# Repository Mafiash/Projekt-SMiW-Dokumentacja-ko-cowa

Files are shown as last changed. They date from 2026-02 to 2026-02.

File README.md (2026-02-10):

# Smart LED - Inteligentny Sysytem Oświetlenia LED

**Autor:** Mateusz Smuda
**Sekcja:** 10 
**Nr albumu:** 312441 
**Rok:** 2025 

## Opis Projektu
Projekt "Smart LED" to system automatycznego sterowania oświetleniem LED WS2812B opartym na mikrokontrolerze ESP32-WROOM-32E. System wykorzystuje zaawansowany radar obecności (LD2410C) zamiast tradycyjnych czujników PIR. Dodatkowo barwa światła dostosowuje się do temperatury otoczenia przy użyciu czujnika DHT22, a jasność świecenia jest regulowana automatycznie w zależności od jasności otoczenia za pomocą fotorezystora.

Układ zarządzany jest przez własny serwer WWW postawiony na ESP32, umożliwiający zdalne sterowanie z poziomu przeglądarki (telefon/komputer).

## Główne Funkcjonalności
- **Wykrywanie obecności:** Radar LD2410C (wykrywanie ruchu i bezruchu).
- **Adaptacja barwna:** Zmiana koloru LED w zależności od temperatury (Niebieski <20°C / Zielony / Czerwony >26°C).
- **Adaptacja jasności:** Automatyczne ściemnianie w nocy i rozjaśnianie w dzień.
- **Interfejs WWW:** Panel sterowania (HTML/JS) z podglądem parametrów na żywo.
- **Tryby pracy:** 
  - **AUTO:** Pełna automatyka sensorowa.
  - **MANUAL:** Ręczne ustawianie koloru (RGB) i jasności suwakiem.

## Wykorzystany Sprzęt
1. **Mikrokontroler:** ESP32-WROOM-32E
2. **Oświetlenie:** Taśma LED adresowalna WS2812B (60 diod)
3. **Sensor ruchu:** Radar HLK-LD2410C
4. **Sensor temp/wilg:** DHT22
5. **Sensor światła:** Moduł z fotorezystorem

## Technologie
- **Język:** C++ (Arduino IDE)
- **Web:** HTML, CSS, JavaScript
- **Biblioteki:** Adafruit NeoPixel, DHT Sensor Library, WiFi.h, WebServer.h

## Instrukcja Uruchomienia
1. Podłącz zasilanie 5V.
2. Połącz się z siecią WiFi.

3. Wpisz w przeglądarce adres IP urządzenia.

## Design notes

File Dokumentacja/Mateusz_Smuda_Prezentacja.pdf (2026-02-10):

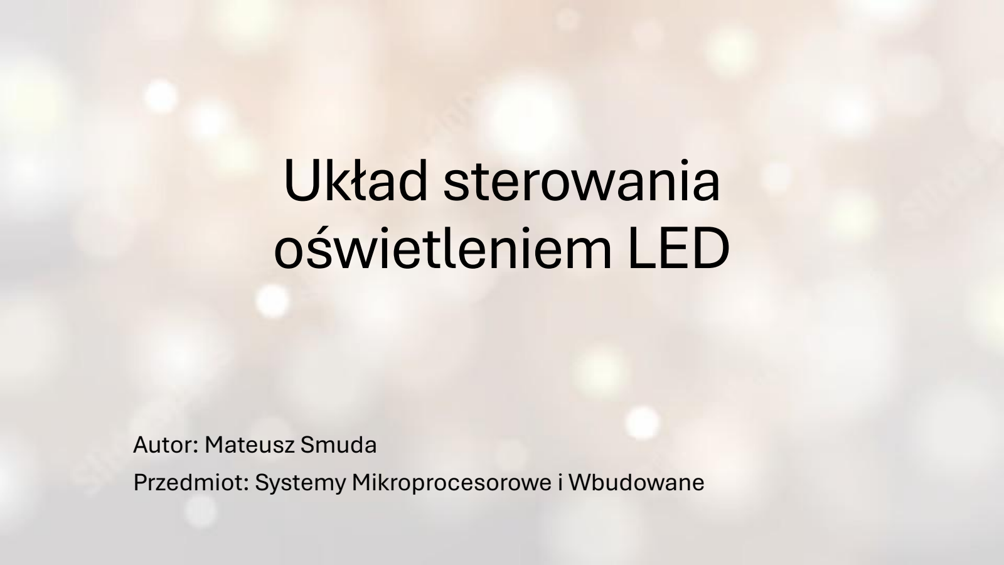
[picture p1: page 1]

# Układ sterowania oświetleniem LED

Autor: Mateusz Smuda
Przedmiot: Systemy Mikroprocesorowe i Wbudowane

## 1. Założenia projektu

- Stworzenie układu sterującego taśmą LED WS2812B.
- Wykorzystanie czujników do automatycznej regulacji zachowania oświetlenia.
- Zmiana koloru LED w zależności od temperatury (DHT22).
- Zmiana jasności w zależności od natężenia światła (fotorezystor).
- Włączanie oświetlenia po wykryciu ruchu przez czujnik LD2410C.
- Dwa tryby pracy: automatyczny i manualny.
- Sterowanie zdalne przez aplikację webową hostowaną na ESP32.

## 2. Analiza układu

- Układ zbiera informacje o temperaturze, natężeniu światła oraz obecności człowieka, a następnie wykorzystuje te dane do odpowiedniego dostosowania barwy i jasności taśmy LED WS2812B.
- System przewiduje dwa tryby pracy: automatyczny i manualny.
- W trybie automatycznym oświetlenie reaguje samoczynnie na dane z czujników
- W trybie manualnym użytkownik sam wybiera parametry światła za pomocą prostej aplikacji webowej. ESP32 pełni rolę jednostki centralnej, obsługuje komunikację z czujnikami oraz generuje sygnały sterujące LED-ami, a dzięki wbudowanemu Wi-Fi umożliwia wygodne sterowanie z poziomu przeglądarki.

## 3. Schemat układu

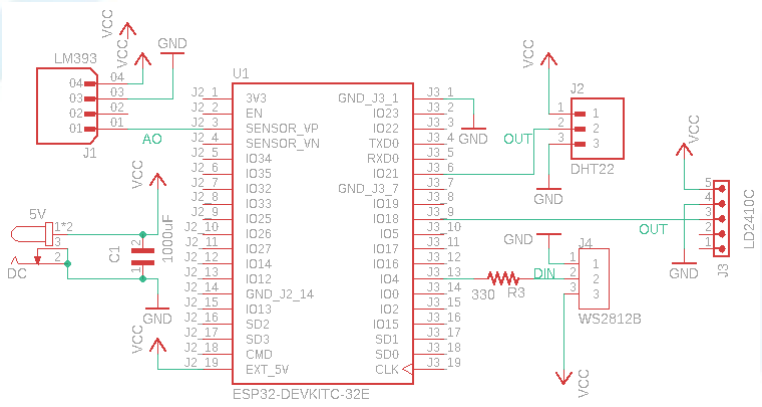
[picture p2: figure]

## 4. Schemat PCB

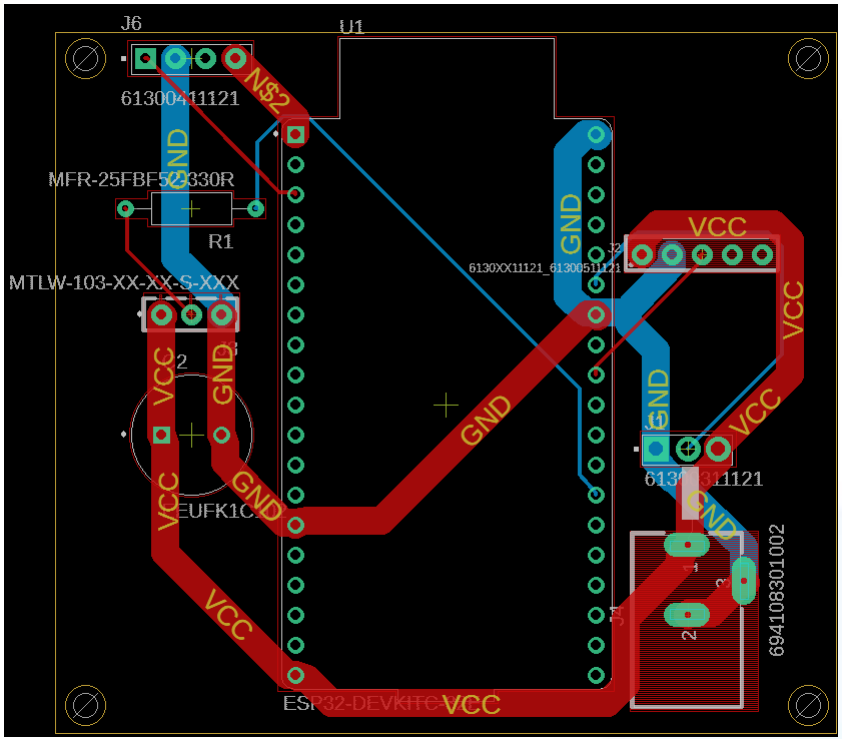
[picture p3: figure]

## 5. Dobór części

- ESP32-WROOM-32E – główny mikrokontroler, obsługa Wi-Fi, sterowanie LED i czujnikami.
- Taśma LED RGB WS2812B – adresowalne diody RGB, umożliwiają płynną zmianę kolorów i efektów.
- Czujnik DHT22(AM2302) – pomiar temperatury i wilgotności, wykorzystany do sterowania barwą LED.
- Czujnik LD2410C – radarowy czujnik ruchu wykrywający obecność osoby.
- Czujnik światła jako moduł wyposażony w fotorezystor – pomiar natężenia światła, regulacja jasności LED.

## ESP32-DevKitC-32E

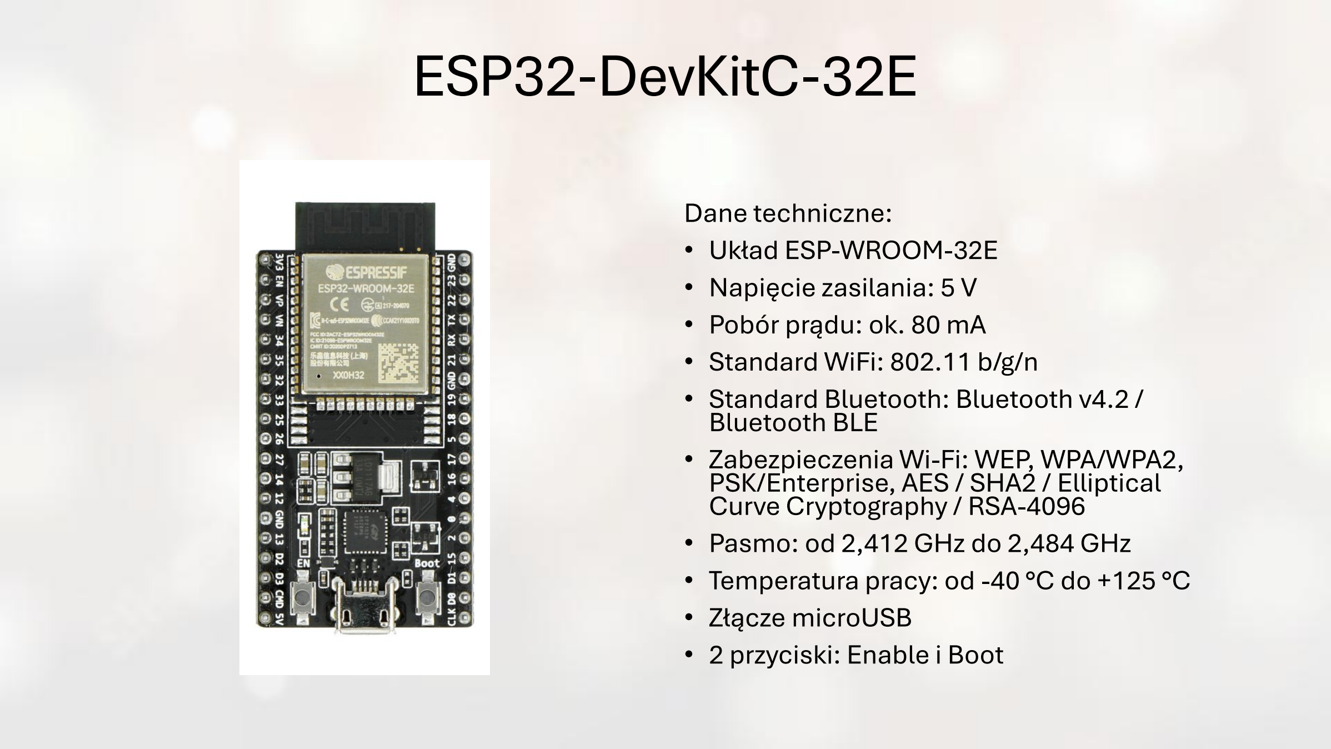
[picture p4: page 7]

Dane techniczne:
- Układ ESP-WROOM-32E
- Napięcie zasilania: 5 V
- Pobór prądu: ok. 80 mA
- Standard WiFi: 802.11 b/g/n
- Standard Bluetooth: Bluetooth v4.2 / Bluetooth BLE
- Zabezpieczenia Wi-Fi: WEP, WPA/WPA2, PSK/Enterprise, AES / SHA2 / Elliptical Curve Cryptography / RSA-4096
- Pasmo: od 2,412 GHz do 2,484 GHz
- Temperatura pracy: od -40 °C do +125 °C
- Złącze microUSB
- 2 przyciski: Enable i Boot

## Taśma LED RGB WS2812B

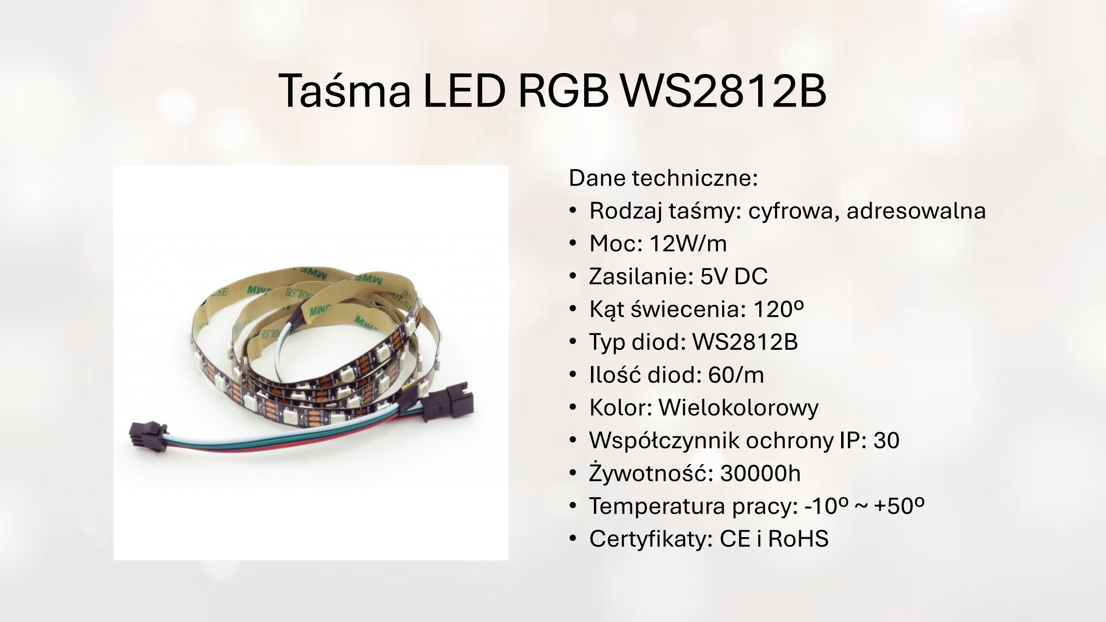
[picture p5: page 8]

Dane techniczne:
- Rodzaj taśmy: cyfrowa, adresowalna
- Moc: 12W/m
- Zasilanie: 5V DC
- Kąt świecenia: 120º
- Typ diod: WS2812B
- Ilość diod: 60/m
- Kolor: Wielokolorowy
- Współczynnik ochrony IP: 30
- Żywotność: 30000h
- Temperatura pracy: -10º ~ +50º
- Certyfikaty: CE i RoHS

## Czujnik AM2302(DHT22)

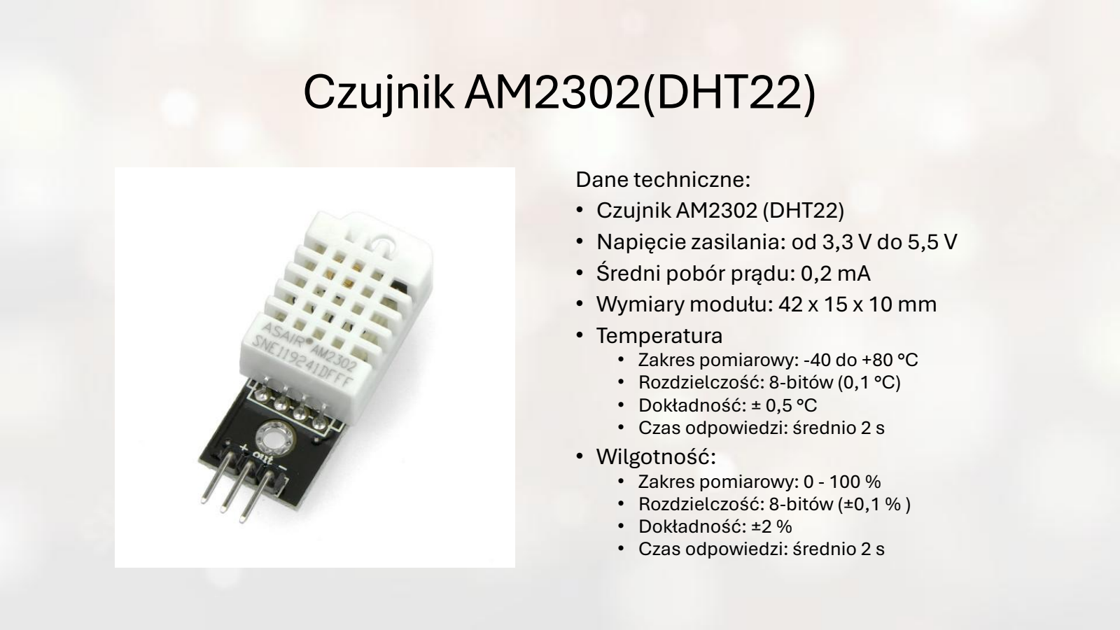
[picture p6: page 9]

Dane techniczne:
- Czujnik AM2302 (DHT22)
- Napięcie zasilania: od 3,3 V do 5,5 V
- Średni pobór prądu: 0,2 mA
- Wymiary modułu: 42 x 15 x 10 mm
- Temperatura
- Zakres pomiarowy: -40 do +80 °C
- Rozdzielczość: 8-bitów (0,1 °C)
- Dokładność: ± 0,5 °C
- Czas odpowiedzi: średnio 2 s
- Wilgotność:
- Zakres pomiarowy: 0 - 100 %
- Rozdzielczość: 8-bitów (±0,1 % )
- Dokładność: ±2 %
- Czas odpowiedzi: średnio 2 s

## Czujnik obecności człowieka HLK-LD2410C

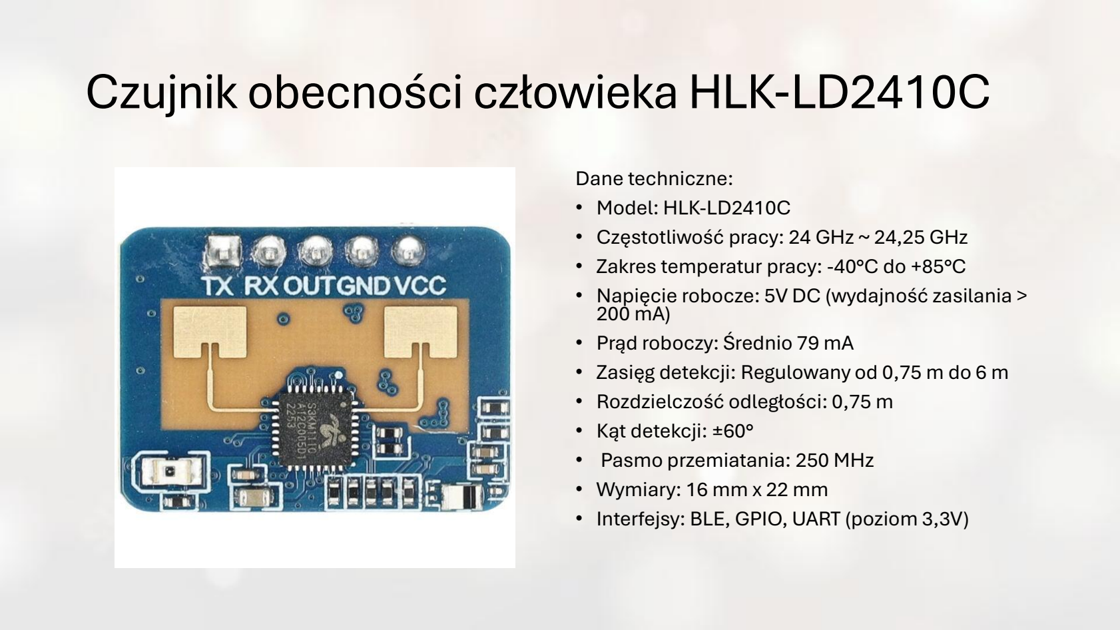
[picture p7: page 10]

Dane techniczne:
- Model: HLK-LD2410C
- Częstotliwość pracy: 24 GHz ~ 24,25 GHz
- Zakres temperatur pracy: -40°C do +85°C
- Napięcie robocze: 5V DC (wydajność zasilania > 200 mA)
- Prąd roboczy: Średnio 79 mA
- Zasięg detekcji: Regulowany od 0,75 m do 6 m
- Rozdzielczość odległości: 0,75 m
- Kąt detekcji: ±60°
- Pasmo przemiatania: 250 MHz
- Wymiary: 16 mm x 22 mm
- Interfejsy: BLE, GPIO, UART (poziom 3,3V)

## Czujnik światła fotorezystor

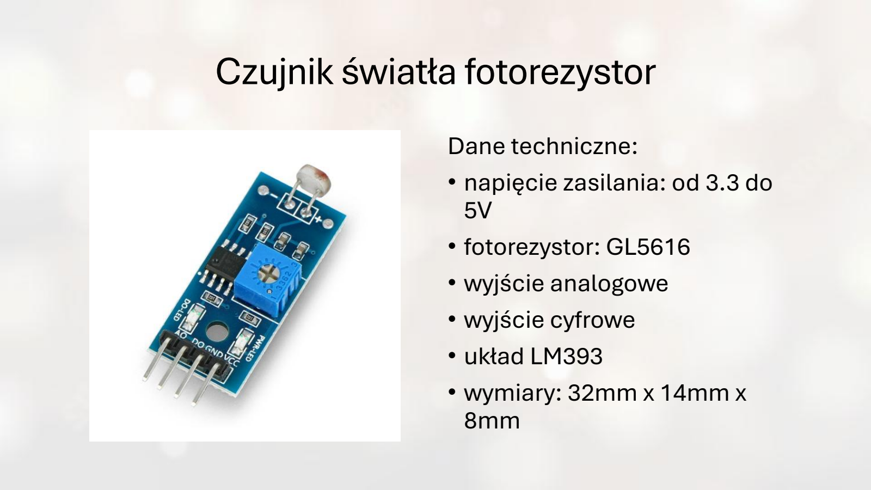
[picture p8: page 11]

Dane techniczne:
- napięcie zasilania: od 3.3 do 5V
- fotorezystor: GL5616
- wyjście analogowe
- wyjście cyfrowe
- układ LM393
- wymiary: 32mm x 14mm x
8mm

## 6. Kosztorys

ESP32-DevKitC-32E | 36 zł
Zasilacz | 50 zł
Czujnik temperatury i wilgotności DHT22 (AM2302) | 45 zł
Czujnik obecności człowieka HLK-LD2410C 24GHz BLE UART | 20 zł
Czujnik światła LDR rezystancyjny | 5 zł
1m taśma WS2812B argb 5V 60 diod/m | 30 zł
Łączna kwota z kosztami dodatkowymi: | 200 zł

## 7. Działanie układu

- Po uruchomieniu systemu ESP32 inicjalizuje taśmę LED, czujniki oraz moduł komunikacyjny Wi-Fi.
- W trybie automatycznym mikrokontroler cyklicznie odczytuje temperaturę, natężenie światła i sygnał z czujnika ruchu. Na tej podstawie dobiera kolor LED zależnie od temperatury oraz ustala jasność odpowiednią do poziomu oświetlenia otoczenia.
- Gdy radar wykryje obecność osoby, taśma LED zostaje automatycznie włączona, a brak ruchu powoduje jej wyłączenie.
- W trybie manualnym logika automatyczna jest pomijana, a ESP32 reaguje jedynie na polecenia użytkownika przesyłane z aplikacji webowej.
- Panel dostępny w przeglądarce pozwala ustawić kolor, jasność i przełączyć tryb pracy. Dzięki temu układ może pracować zarówno jako autonomiczne oświetlenie reagujące na otoczenie, jak i jako źródło światła sterowane zdalnie.

## 8. Instrukcja użytkownika

- Podłącz układ do zasilacza 5 V.
- Po włączeniu ESP32 uruchomi aplikację webową.
- Otwórz przeglądarkę i wejdź na adres IP ESP32.
- Wybierz tryb pracy: automatyczny lub manualny.
- W trybie manualnym ustaw kolor i jasność diod LED.
- W trybie automatycznym układ pracuje samodzielnie, reagując na warunki otoczenia.
- Możliwość monitorowania temperatury, jasności i wykrywania ruchu bezpośrednio w panelu.

## 9. Wnioski

Projekt pozwolił na stworzenie w pełni funkcjonalnego, inteligentnego układu sterowania oświetleniem.
Zastosowanie ESP32 umożliwiło integrację wielu czujników oraz funkcjonalności sieciowych w jednym urządzeniu.
System jest skalowalny i łatwy do rozbudowy o dodatkowe funkcje. Dzięki projektowi poznano praktyczne zastosowanie mikrokontrolerów rodziny ESP32 oraz różnych czujników monitorujących otoczenie.
Projekt umożliwił także zapoznanie się z programem EAGLE 9.6.2 który pozwolił na zaprojektowanie schematu układu oraz płytki PCB.

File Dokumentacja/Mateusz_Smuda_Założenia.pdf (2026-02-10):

Mateusz Smuda, 312441, sekcja 10, 2025
Temat:
Układ sterowania LED z czujnikiem ruchu, czujnikiem temperatury oraz czujnikiem światła Założenia projektu:
- Stworzenie układu sterującego taśmą LED WS2812B.
- Wykorzystanie czujników do automatycznej regulacji zachowania oświetlenia.
- Zmiana koloru LED w zależności od temperatury (DHT22).
- Zmiana jasności w zależności od natężenia światła (fotorezystor).
- Włączanie oświetlenia po wykryciu ruchu przez czujnik LD2410C.
- Dwa tryby pracy: automatyczny i manualny.
- Sterowanie zdalne przez aplikację webową hostowaną na ESP32.
Celem projektu jest stworzenie inteligentnego systemu oświetlenia LED, który łączy funkcje automatycznej regulacji światła z możliwością zdalnego sterowania. Układ zbiera informacje o temperaturze, natężeniu światła oraz wykryciu ruchu, a następnie wykorzystuje te dane do odpowiedniego dostosowania barwy i jasności taśmy LED WS2812B. System przewiduje dwa tryby pracy: automatyczny i manualny. W trybie automatycznym oświetlenie reaguje samoczynnie na dane z czujników, natomiast w trybie manualnym użytkownik sam wybiera parametry światła za pomocą prostej aplikacji webowej. ESP32 pełni rolę jednostki centralnej, obsługuje komunikację z czujnikami oraz generuje sygnały sterujące LED-ami, a dzięki wbudowanemu Wi-Fi umożliwia wygodne sterowanie z poziomu przeglądarki.
Użyte komponenty:
- Płytka rozwojowa z wbudowanym modułem ESP32-WROOM-E
- adresowalny pasek LED(WS2812B)
- czujnik temperatury(DHT22)
- czujnik ruchu(LD2410C)
- czujnik światła(fotorezystor)

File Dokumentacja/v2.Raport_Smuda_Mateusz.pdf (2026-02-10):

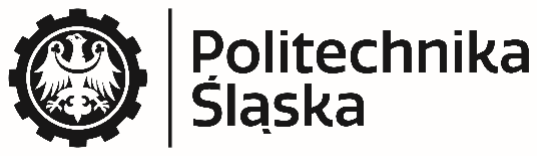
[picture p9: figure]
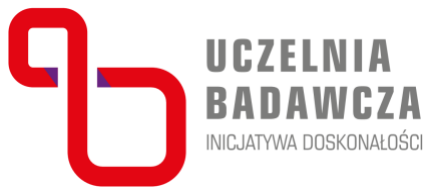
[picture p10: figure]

# Raport końcowy

Rodzaj zajęć

# Projekt

Przedmiot

# Systemy Mikroprocesorowe i Wbudowane

Rok akademicki | Miasto | Kierunek | Semestr | Prowadzący | Grupa | Sekcja
2025/2026 | G | INF | 5 | GB | 5 | 10
Planowany termin wykonywania ćwiczenia | Faktyczny termin wykonania ćwiczenia
Data | Godzina | Data | Godzina
02.02.2026 | 14:00
Numer ćwiczenia | Temat ćwiczenia
| Układ sterowania oświetleniem LED

Skład sekcji
| Imię i nazwisko | Uwagi
1 | Mateusz Smuda

1. Temat projektu i opis założeń z opisem funkcji urządzenia.

Temat:

Układ sterowania LED z czujnikiem ruchu, czujnikiem temperatury oraz czujnikiem światła

Założenia projektu:

- Stworzenie układu sterującego taśmą LED WS2812B.
- Wykorzystanie czujników do automatycznej regulacji zachowania oświetlenia.
- Zmiana koloru LED w zależności od temperatury (DHT22).
- Zmiana jasności w zależności od natężenia światła (fotorezystor).
- Włączanie oświetlenia po wykryciu ruchu przez czujnik LD2410C.
- Dwa tryby pracy: automatyczny i manualny.
- Sterowanie zdalne przez aplikację webową hostowaną na ESP32.

### 2. Analiza zadania z uzasadnieniem wyboru elementów elektronicznych i narzędzi użytych do

realizacji projektu.

Celem projektu jest stworzenie inteligentnego systemu oświetlenia LED, który łączy funkcje automatycznej regulacji światła z możliwością zdalnego sterowania. Układ zbiera informacje o temperaturze, natężeniu światła oraz wykryciu ruchu, a następnie wykorzystuje te dane do odpowiedniego dostosowania barwy i jasności taśmy LED WS2812B. System przewiduje dwa tryby pracy: automatyczny i manualny. W trybie automatycznym oświetlenie reaguje samoczynnie na dane z czujników, natomiast w trybie manualnym użytkownik sam wybiera parametry światła za pomocą prostej aplikacji webowej. ESP32 pełni rolę jednostki centralnej, obsługuje komunikację z czujnikami oraz generuje sygnały sterujące LED-ami, a dzięki wbudowanemu Wi-Fi umożliwia wygodne sterowanie z poziomu przeglądarki.

Do realizacji projektu wybrano mikrokontroler ESP32 ze względu na:

- wbudowany moduł Wi-Fi,
- dużą liczbę wejść/wyjść,
- wysoką wydajność,
- szerokie wsparcie bibliotek programistycznych.

Taśma LED WS2812B została wybrana ze względu na możliwość indywidualnego adresowania diod, co pozwala na precyzyjną kontrolę koloru i jasności przy użyciu jednego pinu sterującego.

Czujnik LD2410C wykorzystuje technologię radarową, co umożliwia wykrywanie obecności człowieka niezależnie od warunków oświetleniowych, wybrany został przez swoją precyzję pomiarów i możliwość wygodnego dostosowywania parametrów.

Czujnik DHT22 umożliwia pomiar temperatury został on wybrany za dokładność i możliwość łatwego montażu.

Moduł fotorezystora pozwala na ocenę poziomu oświetlenia otoczenia został wybrany z powodu łatwości obsługi.

Do programowania wykorzystano środowisko Arduino IDE, które umożliwia szybkie prototypowanie oraz łatwą integrację bibliotek obsługujących zastosowane komponenty.

### 3. Specyfikacja wewnętrzna:

a. Schemat blokowy i ideowy urządzenia.

Schemat blokowy:

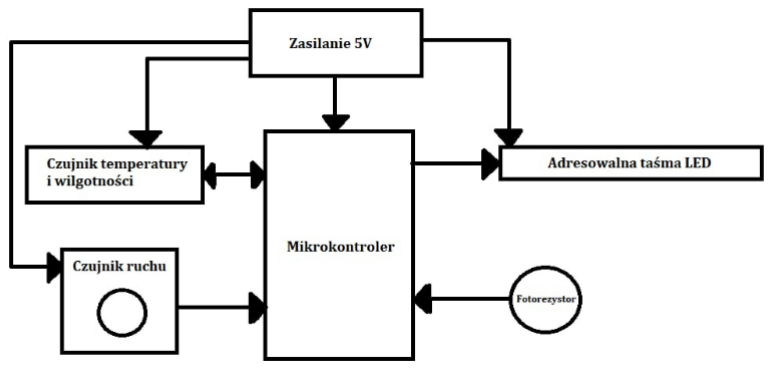
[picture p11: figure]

Schemat ideowy z podpisanymi modułami bez prowadzenia długich ścieżek w celu lepszej widoczności i sprawdzenia poprawności układu:

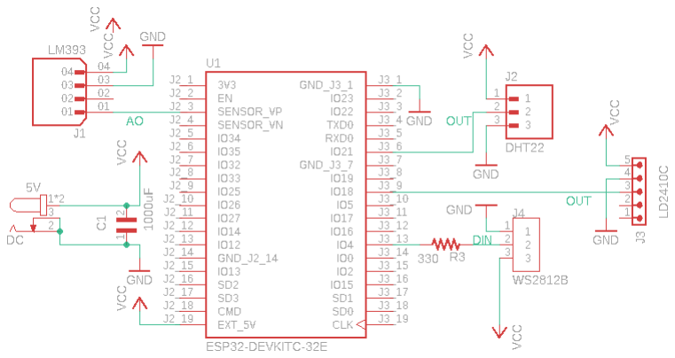
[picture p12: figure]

Schematu użyty do zaprojektowania płytki PCB ze ścieżkami:

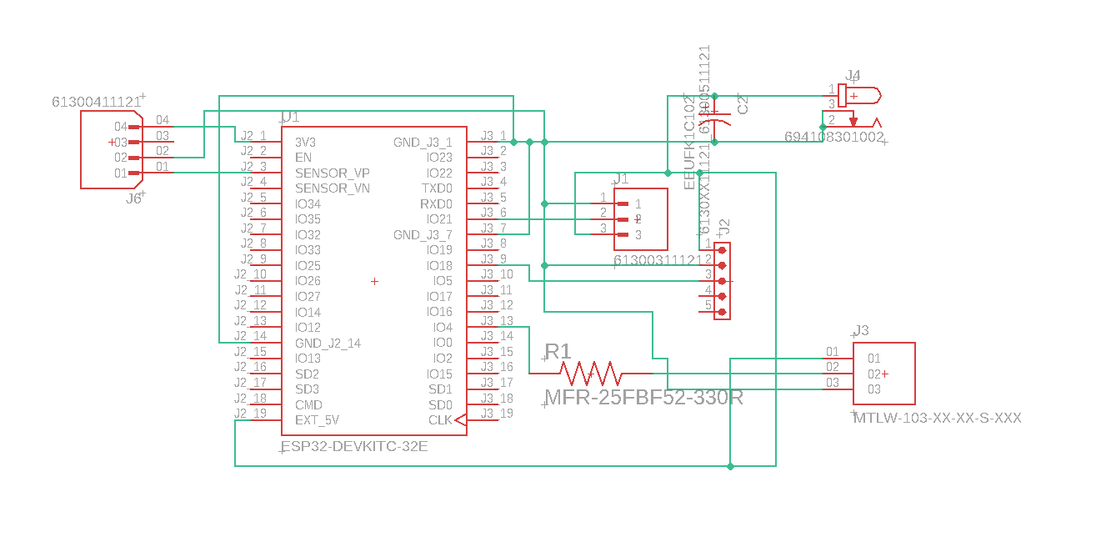
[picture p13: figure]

b. Opis funkcji poszczególnych bloków układu, szczegółowy opis działania ważniejszych elementów układu.

ESP32 – jednostka centralna systemu, przetwarza dane z czujników, steruje diodami LED oraz obsługuje komunikację Wi-Fi.

LD2410C – czujnik ruchu, generuje sygnał informujący o wykryciu ruchu.

DHT22 – czujnik temperatury, dostarcza danych do regulacji koloru LED.

Fotorezystor – mierzy poziom światła otoczenia, na podstawie którego regulowana jest jasność LED.

WS2812B – element generujący światło zgodnie z pomiarami czujników.

c. Schemat montażowy obejmujący projekt płytki drukowanej, rozmieszczenie elementów na płytce.

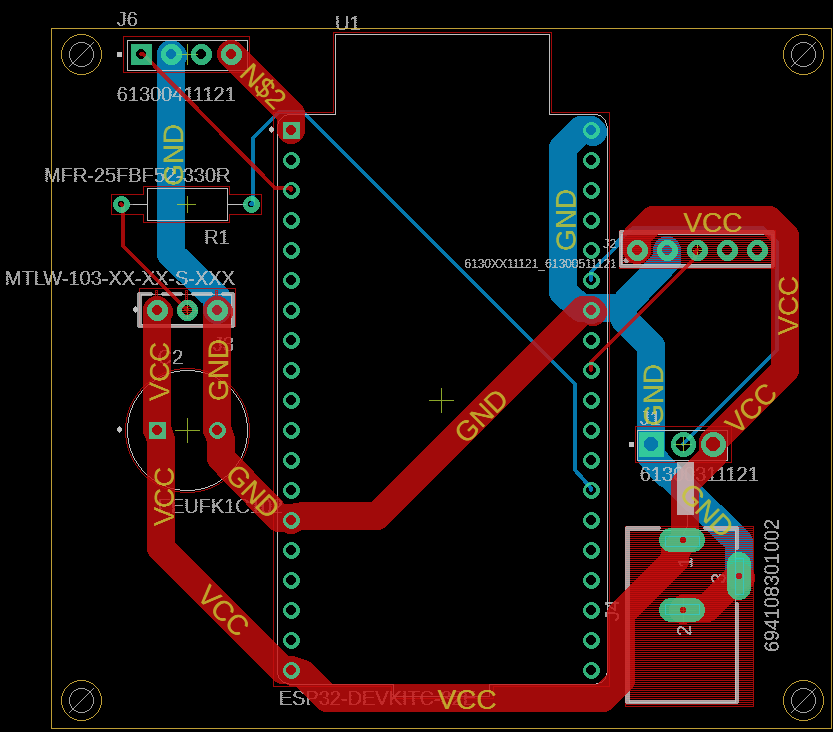
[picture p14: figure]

Lista elementów:

ESP32-DEVKITC-32E

694108301002 – złącze zasilania DC 2.5mm/5.5mm

Złącza goldpin męskie 3 pin/4 pin oraz 5 pin o rastrze 2.54mm do podpięcia czujników(DNT22,LD2410C,moduł fotorezystor) oraz adresowalnego paska LED WS2812B

Rezystor 330Ohm

Kondensator 1000uF

d. Algorytm oprogramowania urządzenia

Algorytm działania oprogramowania opiera się na pętli głównej programu, w której mikrokontroler ESP32 cyklicznie obsługuje komunikację sieciową, odczytuje dane z czujników oraz steruje taśmą LED. Po uruchomieniu urządzenia następuje inicjalizacja mikroprocesora, czujników oraz połączenia Wi-Fi. Następnie uruchamiany jest serwer WWW, który udostępnia panel sterowania użytkownikowi.

W głównej pętli programu realizowane są następujące kroki:

1. Obsługa żądań HTTP z aplikacji webowej.
2. Cykliczny odczyt temperatury, natężenia światła oraz stanu czujnika ruchu.

3. Sprawdzenie aktualnego trybu pracy (automatyczny lub manualny).
4. W trybie automatycznym – obliczenie koloru i jasności LED na podstawie danych z czujników.
5. W trybie manualnym – ustawienie parametrów LED zgodnie z poleceniami użytkownika.
6. Aktualizacja stanu taśmy LED.

Główny kod programu do sterowania:

#include <WiFi.h>

#include <WebServer.h>

#include <Adafruit_NeoPixel.h> #include <DHT.h>

#include "index.h"

const char* ssid = "HUAWEI Mate 10 Pro"; const char* password = "59befa2de9a3";

#define LED_PIN | 4

#define RADAR_PIN | 18

#define DHT_PIN | 21

#define LDR_PIN | 36

#define NUM_PIXELS 60

#define DHT_TYPE DHT22

Adafruit_NeoPixel pixels(NUM_PIXELS, LED_PIN, NEO_GRB + NEO_KHZ800); DHT dht(DHT_PIN, DHT_TYPE);
WebServer server(80);

const unsigned long CZAS_SWIECENIA = 10000; unsigned long ostatniRuchCzas = 0; unsigned long ostatniOdczytSensorow = 0;

bool trybAuto = true;
bool manualState = false;
uint32_t manualColor = 0;
int manualBrightness = 50;

float temperatura = 0.0;
int jasnoscLDR = 0;
bool wykrytoRuch = false;

void setup() {
Serial.begin(9600);

pinMode(RADAR_PIN, INPUT_PULLDOWN); pinMode(LDR_PIN, INPUT);

dht.begin();
pixels.begin();
pixels.setBrightness(100); pixels.show();

Serial.print("Łączenie z WiFi"); WiFi.begin(ssid, password);
while (WiFi.status() != WL_CONNECTED) { delay(500);
Serial.print(".");
}
Serial.println("\nPołączono!"); Serial.print("Adres IP strony: http://"); Serial.println(WiFi.localIP());

server.on("/", []() {
server.send(200, "text/html", index_html); });

server.on("/status", []() {
String json = "{";
json += "\"temp\":" + String(temperatura) + ","; json += "\"ldr\":" + String(jasnoscLDR) + ","; json += "\"radar\":" + String(wykrytoRuch) + ","; json += "\"modeAuto\":" + String(trybAuto); json += "}";
server.send(200, "application/json", json);
});

server.on("/set", handleControl);

server.begin();
}

void loop() {
server.handleClient();

unsigned long aktualnyCzas = millis();

if (aktualnyCzas - ostatniOdczytSensorow > 2000) { float t = dht.readTemperature();
if (!isnan(t)) temperatura = t;

jasnoscLDR = analogRead(LDR_PIN);

wykrytoRuch = (digitalRead(RADAR_PIN) == HIGH);

ostatniOdczytSensorow = aktualnyCzas;

}

if (trybAuto) {
logikaAutomatyczna(aktualnyCzas); } else {
logikaManualna();
}
}

void logikaAutomatyczna(unsigned long czas) { int stanRadaru = digitalRead(RADAR_PIN);

if (stanRadaru == HIGH) {
ostatniRuchCzas = czas;
}

if (czas - ostatniRuchCzas < CZAS_SWIECENIA) {

uint32_t kolor;
if (temperatura < 20.0) | kolor = pixels.Color(0, 0, 255);
else if (temperatura > 26.0) kolor = pixels.Color(255, 0, 0);
else | kolor = pixels.Color(0, 255, 0);

int jasnoscPWM = map(jasnoscLDR, 0, 4095, 255, 10); jasnoscPWM = constrain(jasnoscPWM, 10, 255);

pixels.setBrightness(jasnoscPWM); fillStrip(kolor);

} else {
pixels.clear();
pixels.show();
}
}

void logikaManualna() {
pixels.setBrightness(manualBrightness);

if (manualState) {
if (manualColor == 0) manualColor = pixels.Color(255, 255, 255); fillStrip(manualColor);
} else {
pixels.clear();
pixels.show();
}
}

void handleControl() {
if (server.hasArg("mode")) {

String m = server.arg("mode");
if (m == "auto") trybAuto = true; if (m == "manual") trybAuto = false; }

if (server.hasArg("manual")) {
manualState = (server.arg("manual").toInt() == 1); }

if (server.hasArg("brightness")) {
manualBrightness = server.arg("brightness").toInt(); }

if (server.hasArg("color")) {
String hex = server.arg("color");
long number = strtol(hex.c_str(), NULL, 16); int r = number >> 16;
int g = (number >> 8) & 0xFF;
int b = number & 0xFF;
manualColor = pixels.Color(r, g, b); }
server.send(200, "text/plain", "OK"); }

void fillStrip(uint32_t color) { for(int i=0; i<NUM_PIXELS; i++) { pixels.setPixelColor(i, color); }
pixels.show();
}

Kod interfejsu strony internetowej:

const char index_html[] PROGMEM = R"rawliteral( <!DOCTYPE html>
<html lang="pl">
<head>
<meta charset="UTF-8">
<meta name="viewport" content="width=device-width, initial-scale=1"> <title>Smart Schody - Panel</title>
<style>
body { font-family: 'Segoe UI', Arial, sans-serif; background-color: #1a1a1a; color: #f0f0f0; text-align: center; margin: 0; padding: 20px; } h1 { color: #00d2ff; margin-bottom: 5px; }
h3 { color: #aaa; margin-top: 0; }

.card { background-color: #2d2d2d; max-width: 400px; margin: 20px auto; padding: 25px; border-radius: 15px; box-shadow: 0 10px 20px rgba(0,0,0,0.5); }

.sensor-grid { display: grid; grid-template-columns: 1fr 1fr; gap: 15px; margin-bottom: 20px; }
.sensor-box { background: #383838; padding: 15px; border-radius: 10px; } .val { font-size: 1.8rem; font-weight: bold; color: #fff; }
.label { font-size: 0.9rem; color: #888; }

.btn-group { display: flex; justify-content: center; gap: 10px; margin: 20px 0; }
button { padding: 12px 20px; font-size: 16px; border: none; border-radius: 8px; cursor: pointer; transition: 0.2s; font-weight: bold; width: 100%; }

.active { border: 2px solid white; transform: scale(1.05); }
.btn-auto { background-color: #007bff; color: white; }
.btn-man { background-color: #ffc107; color: black; }

.manual-controls { background: #444; padding: 15px; border-radius: 10px; margin-top: 15px; }
.toggle-btn { padding: 15px; width: 100%; margin-bottom: 10px; font-size: 1.2rem; }
.on { background-color: #28a745; color: white; }
.off { background-color: #dc3545; color: white; }

input[type="color"] { width: 100%; height: 50px; border: none; cursor: pointer; border-radius: 5px; }
input[type=range] { width: 100%; margin: 10px 0; }
</style>
</head>
<body>

<h1>Smart Schody</h1>
<h3>Panel Sterowania</h3>

<div class="card">
<div class="sensor-grid">
<div class="sensor-box">
<div class="label">Temperatura</div>
<div class="val"><span id="temp">--</span> °C</div> </div>
<div class="sensor-box">
<div class="label">Jasność (LDR)</div>
<div class="val"><span id="ldr">--</span></div> </div>
</div>

<div style="font-size: 0.9rem; color: #bbb; margin-bottom: 15px;">
Status Radaru: <span id="radar" style="font-weight:bold; color:orange">--</span>
</div>

<hr style="border-color: #444;">

<div class="btn-group">
<button id="btnAuto" class="btn-auto" onclick="setMode('auto')">TRYB AUTO</button>
<button id="btnMan" class="btn-man" onclick="setMode('manual')">TRYB RĘCZNY</button>
</div>

<div id="manualPanel" class="manual-controls" style="display:none;"> <button id="mainSwitch" class="toggle-btn off" onclick="toggleLed()">LED: WYŁĄCZONE</button>
<label style="display:block; margin: 10px 0 5px;">Wybierz Kolor:</label> <input type="color" id="colorPicker" value="#ffffff" onchange="updateColor()">
<label style="display:block; margin: 15px 0 5px;">Jasność: <span id="brightVal">50</span></label>
<input type="range" min="10" max="255" value="50" id="brightSlider" oninput="updateBrightness(this.value)" onchange="updateBrightness(this.value)">
</div>
</div>

<script>
let isManualOn = false;

setInterval(getData, 1500);

function getData() {
fetch('/status').then(response => response.json()).then(data => { document.getElementById("temp").innerText = data.temp.toFixed(1); document.getElementById("ldr").innerText = data.ldr; document.getElementById("radar").innerText = data.radar ? "Wykryto Ruch" : "Czuwanie";

if (data.modeAuto) {
document.getElementById("btnAuto").classList.add("active"); document.getElementById("btnMan").classList.remove("active"); document.getElementById("manualPanel").style.display = "none"; } else {
document.getElementById("btnAuto").classList.remove("active"); document.getElementById("btnMan").classList.add("active"); document.getElementById("manualPanel").style.display = "block"; }
});
}

function setMode(mode) {

fetch('/set?mode=' + mode); setTimeout(getData, 200);
}

function toggleLed() {
isManualOn = !isManualOn;
let btn = document.getElementById("mainSwitch"); if(isManualOn) {
btn.innerText = "LED: WŁĄCZONE"; btn.className = "toggle-btn on"; fetch('/set?manual=1');
} else {
btn.innerText = "LED: WYŁĄCZONE"; btn.className = "toggle-btn off"; fetch('/set?manual=0');
}
}

function updateColor() {
var color = document.getElementById("colorPicker").value.substring(1); fetch('/set?color=' + color);
if(!isManualOn) toggleLed();
}

function updateBrightness(val) { document.getElementById("brightVal").innerText = val; fetch('/set?brightness=' + val);
if(!isManualOn) toggleLed();
}

window.onload = getData;
</script>
</body>
</html>
)rawliteral";
e. Opis wszystkich zmiennych.
- ssid, password – dane sieci Wi-Fi, do której łączy się ESP32.
- LED_PIN – pin sterujący taśmą WS2812B.
- RADAR_PIN – pin wejściowy podłączony do wyjścia OUT czujnika LD2410C.
- DHT_PIN – pin komunikacyjny czujnika DHT22.
- LDR_PIN – wejście analogowe do pomiaru natężenia światła.
- NUM_PIXELS – liczba diod LED w taśmie.
- CZAS_SWIECENIA – czas świecenia LED po ostatnim wykryciu ruchu.
- ostatniRuchCzas – czas ostatniego wykrycia ruchu.
- ostatniOdczytSensorow – znacznik czasu ostatniego odczytu czujników.
- trybAuto – flaga określająca tryb pracy (automatyczny/manualny).

- manualState – stan włączenia LED w trybie manualnym.
- manualColor – kolor ustawiony przez użytkownika.
- manualBrightness – jasność ustawiona przez użytkownika.
- temperatura – aktualna wartość temperatury.
- jasnoscLDR – aktualny poziom oświetlenia otoczenia.
- wykrytoRuch – informacja o wykryciu obecności.
f. Opis funkcji wszystkich procedur.
- setup() – inicjalizacja pinów, czujników, taśmy LED, połączenia Wi-Fi oraz serwera WWW
- loop() – główna pętla programu, obsługa serwera, odczyt czujników oraz wybór logiki działania.
- logikaAutomatyczna() – realizuje automatyczne sterowanie LED na podstawie czujników.
- logikaManualna() – steruje LED zgodnie z ustawieniami użytkownika.
- handleControl() – obsługuje polecenia przesyłane z aplikacji webowej.
- fillStrip() – ustawia jednolity kolor na całej taśmie LED.
g. Opis interakcji oprogramowania z układem elektronicznym

Radar LD2410 (Wejście cyfrowe): mikrokontroler odczytuje stan wysoki/niski na pinie GPIO 18. Zastosowano programowy rezystor ściągający (INPUT_PULLDOWN), aby wyeliminować zakłócenia elektromagnetyczne na przewodzie sygnałowym (tzw. stany nieustalone).

Fotorezystor (Wejście analogowe): przetwornik ADC na pinie GPIO 36 zamienia napięcie (zależne od natężenia światła) na wartość cyfrową 0-4095.

DHT22 (Wejście cyfrowe): biblioteka DHT komunikuje się z czujnikiem na pinie GPIO 21, pobierając ramki danych o temperaturze.

Diody WS2812B (Wyjście cyfrowe): pin GPIO 4 generuje szybki sygnał cyfrowy, sterujący każdą diodą indywidualnie.

Komunikacja z użytkownikiem realizowana jest przez interfejs Wi-Fi i serwer WWW, który umożliwia zdalne sterowanie urządzeniem.

h. Szczegółowy opis działania ważniejszych procedur.

Kluczową procedurą jest logikaAutomatyczna(), która analizuje dane z czujników i decyduje o włączeniu lub wyłączeniu oświetlenia.

- Sprawdza stan radaru. Jeśli jest wysoki (HIGH), aktualizuje zmienną ostatniRuchCzas na bieżący czas systemowy. To mechanizm który powoduje, że światło nie zgaśnie, dopóki wykrywany jest ruch.
- Oblicza różnicę czasu (aktualnyCzas - ostatniRuchCzas). Jeśli jest mniejsza niż
CZAS_SWIECENIA (10s), światło jest włączane.
- Algorytm doboru barwy: Na podstawie zmiennej temperatura wybierany jest kolor: Niebieski (<20°C), Zielony (20-26°C) lub Czerwony (>26°C).
- Algorytm doboru jasności: Funkcja map() przelicza odwróconą logikę fotorezystora (gdzie 0 to jasno, a 4095 to ciemno) na wypełnienie PWM diod (10-255). Ciemniej w pokoju = słabsze świecenie diod, aby nie oślepiać użytkownika.

### 5. Specyfikacja zewnętrzna:

a. Opis funkcji elementów sterujących urządzeniem.

Urządzenie nie posiada fizycznych przycisków. Sterowanie odbywa się wyłącznie poprzez Interfejs WWW dostępny w przeglądarce pod adresem IP urządzenia. Elementy interfejsu:

- Przyciski Trybu: "TRYB AUTO" i "TRYB RĘCZNY" – przełączają logikę działania.
- Przełącznik LED (w trybie ręcznym): Włącza/wyłącza oświetlenie na stałe.
- Paleta Kolorów: Pozwala wybrać dowolną barwę światła z palety RGB.
- Suwak Jasności: Płynna regulacja natężenia światła w zakresie 10-100%.
b. Opis funkcji elementów wykonawczych.

Pasek LED WS2812B: Sygnalizuje ruch, oświetla otoczenie, informuje kolorem o temperaturze otoczenia a także ma odpowiednia jasność w zależności od jasności otoczenia.

Wyświetlacz wirtualny (Panel WWW): Prezentuje dane w czasie rzeczywistym: temperaturę, poziom oświetlenia, status wykrycia ruchu oraz aktualny tryb pracy.

c. Opis reakcji oprogramowania na zdarzenia zewnętrzne.

Wykrycie ruchu powoduje włączenie oświetlenia (z opóźnieniem wynikającym jedynie z czasu reakcji pętli loop).

Brak ruchu przez określony czas powoduje wyłączenie oświetlenia.

Zmiana temperatury zmiana koloru LED.

Zmiana natężenia światła powoduje zmianę jasności LED.

Interakcja użytkownika na stronie czyli wywołanie żądania HTTP powoduje natychmiastowe przerwanie pętli oczekiwania i aktualizację parametrów (np. zmianę koloru).

d. Skrócona instrukcja obsługi urządzenia.
1. Podłącz układ do zasilacza 5 V.
2. Po włączeniu ESP32 uruchomi aplikację webową.
3. Otwórz przeglądarkę i wejdź na adres IP ESP32.
4. W panelu jest wyświetlana temperatura i jasność.
5. Wybierz tryb pracy: automatyczny lub manualny, domyślnie jest automatyczny.
6. W trybie manualnym ustaw kolor i jasność diod LED.
7. W trybie automatycznym układ pracuje samodzielnie, reagując na warunki otoczenia.
6. Opis montażu i uruchamiania.
a. Problemy które wystąpiły podczas montażu i uruchamiania i jak zostały rozwiązane.

Podczas uruchamiania prototypu napotkano następujące problemy:

Radar LD2410 wykazywał fałszywe wykrycia ruchu

Przyczyna: Przewód sygnałowy zbierał zakłócenia, dodatkowo radar był zbyt czuły.

Rozwiązanie: W kodzie programu zmieniono konfigurację pinu na INPUT_PULLDOWN (programowe ściągnięcie do masy). Dodatkowo zmniejszono czułość i czas podtrzymania radaru za pomocą dedykowanej aplikacji HLKRadarTool. Po wprowadzeniu tych zmian układ zaczął działać poprawnie.

b. Testy poprawności działania urządzenia.

Test czujnika ruchu: Wielokrotne wejście i wyjście z pola widzenia. Zmierzono czas podtrzymania (suma czasu radaru + 10s z programu) – wynik powtarzalny, ok. 15-20 sekund.

Test termostatu: Podgrzanie czujnika DHT powyżej 26°C od temperatury 18°C. Zaobserwowano zmianę koloru z niebieskiego na zielony a następnie z zielonego na czerwony. Przy ochładzaniu działanie było także poprawne.

Test optyczny: Weryfikacja działania fotorezystora polegała na symulacji skrajnych warunków oświetleniowych poprzez zasłonięcie czujnika oraz oświetlenie go silnym źródłem światła. Potwierdzono, że układ prawidłowo interpretuje zmiany natężenia światła, płynnie dostosowując jasność diod LED zgodnie z zadanym algorytmem.

Test zdalnego sterowania: Szybkie przełączanie kolorów z poziomu telefonu. Reakcja układu była natychmiastowa.

Test stabilności: Pozostawienie układu w trybie Auto na dłuższy czas, brak samoistnych restartów czy zawieszeń.

7. Wnioski z uruchamiania i testowania.

Projekt pozwolił na stworzenie w pełni funkcjonalnego, inteligentnego układu sterowania oświetleniem. Urządzenie działa stabilnie i poprawnie reaguje na warunki otoczenia oraz polecenia użytkownika. Projekt potwierdził możliwość stworzenia kompletnego systemu IoT z wykorzystaniem ESP32, czujników oraz aplikacji webowej. Rozwiązanie może być w przyszłości rozbudowane o dodatkowe funkcje i czujniki.

Dzięki projektowi poznano praktyczne zastosowanie mikrokontrolerów rodziny ESP32 oraz różnych czujników monitorujących otoczenie.

Projekt umożliwił także zapoznanie się z programem EAGLE 9.6.2 który pozwolił na zaprojektowanie schematu układu oraz płytki PCB a także możliwość nauczenia się prawidłowego lutowania.

### 8. Dokumentacja końcowa linki do repozytorium GitHub oraz OneDrive:

https://polslpl-my.sharepoint.com/:u:/g/personal/ms312441_student_polsl_pl/IQBQrLTVvfDITqE24JqIsPGXAQWKgct2j_YSh-mz-jeS5a4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 (https://polslpl-my.sharepoint.com/:u:/g/personal/ms312441_student_polsl_pl/IQBQrLTVvfDITqE24JqIsPGXAQWKgct2j_YSh-mz-jeS5a4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)

https://github.com/Mafiash/Projekt-SMiW-Dokumentacja-ko-cowa

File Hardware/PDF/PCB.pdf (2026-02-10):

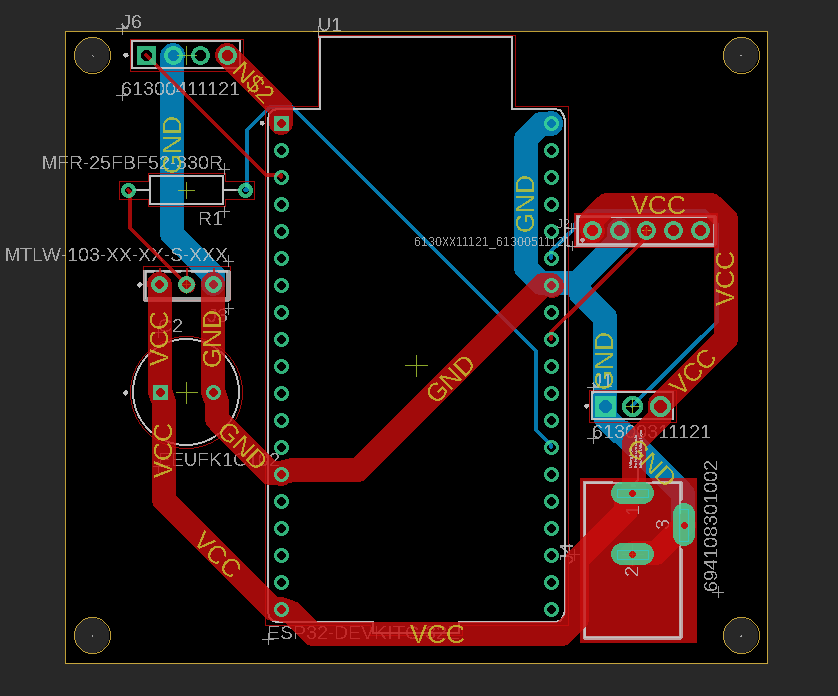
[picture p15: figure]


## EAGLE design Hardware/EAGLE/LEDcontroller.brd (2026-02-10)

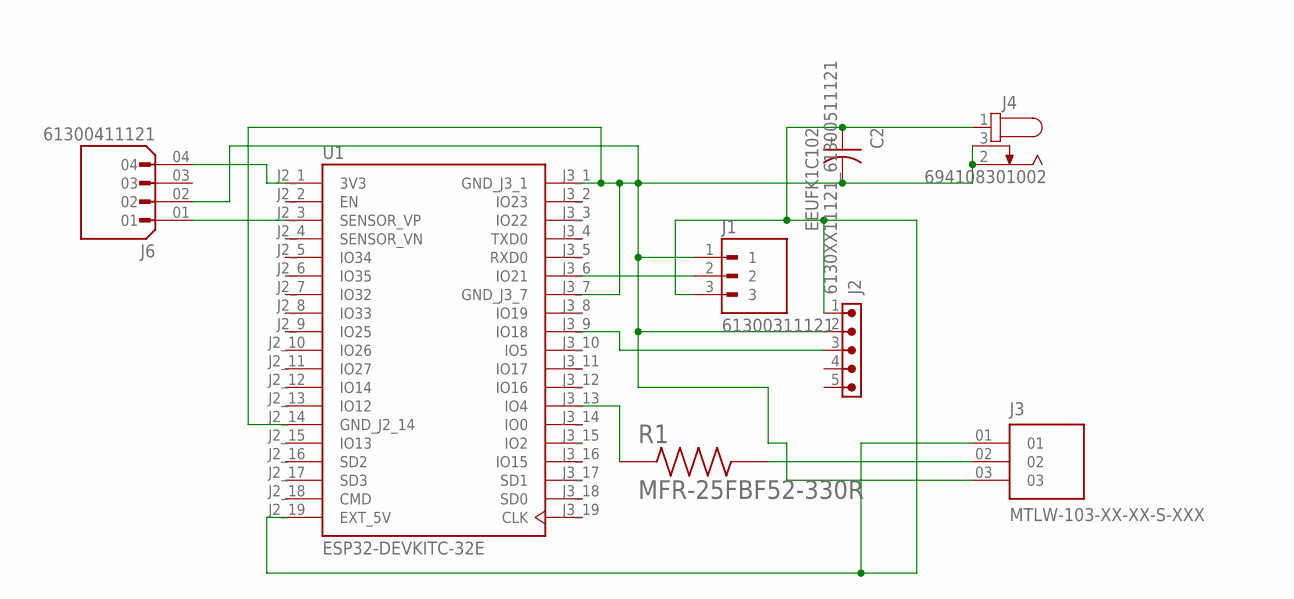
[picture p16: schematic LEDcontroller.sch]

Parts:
C2: EEUFK1C102; CAPPRD500W60D1000H1600
J1: 61300311121; WURTH_61300311121
J2: 6130XX11121_61300511121; 61300511121
J3: MTLW-103-XX-XX-S-XXX; SAMTEC_MTLW-103-XX-XX-S-XXX
J4: 694108301002
J6: 61300411121; WURTH_61300411121
R1: MFR-25FBF52-330R; RESAD1100W55L680D260
U1: ESP32-DEVKITC-32E; MODULE_ESP32-DEVKITC-32E

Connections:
GND: C2.N, J1.1, J2.2, J3.03, J4.2, J4.3, J6.02, U1.J2_14 (GND_J2_14), U1.J3_1 (GND_J3_1), U1.J3_7 (GND_J3_7)
unnamed: J2.3, U1.J3_9 (IO18)
unnamed: J6.04, U1.J2_1 (3V3)
unnamed: J1.2, U1.J3_6 (IO21)
unnamed: J3.02, R1.2
unnamed: J6.01, U1.J2_3 (SENSOR_VP)
unnamed: R1.1, U1.J3_13 (IO4)
VCC: C2.P, J1.3, J2.1, J3.01, J4.1, U1.J2_19 (EXT_5V)

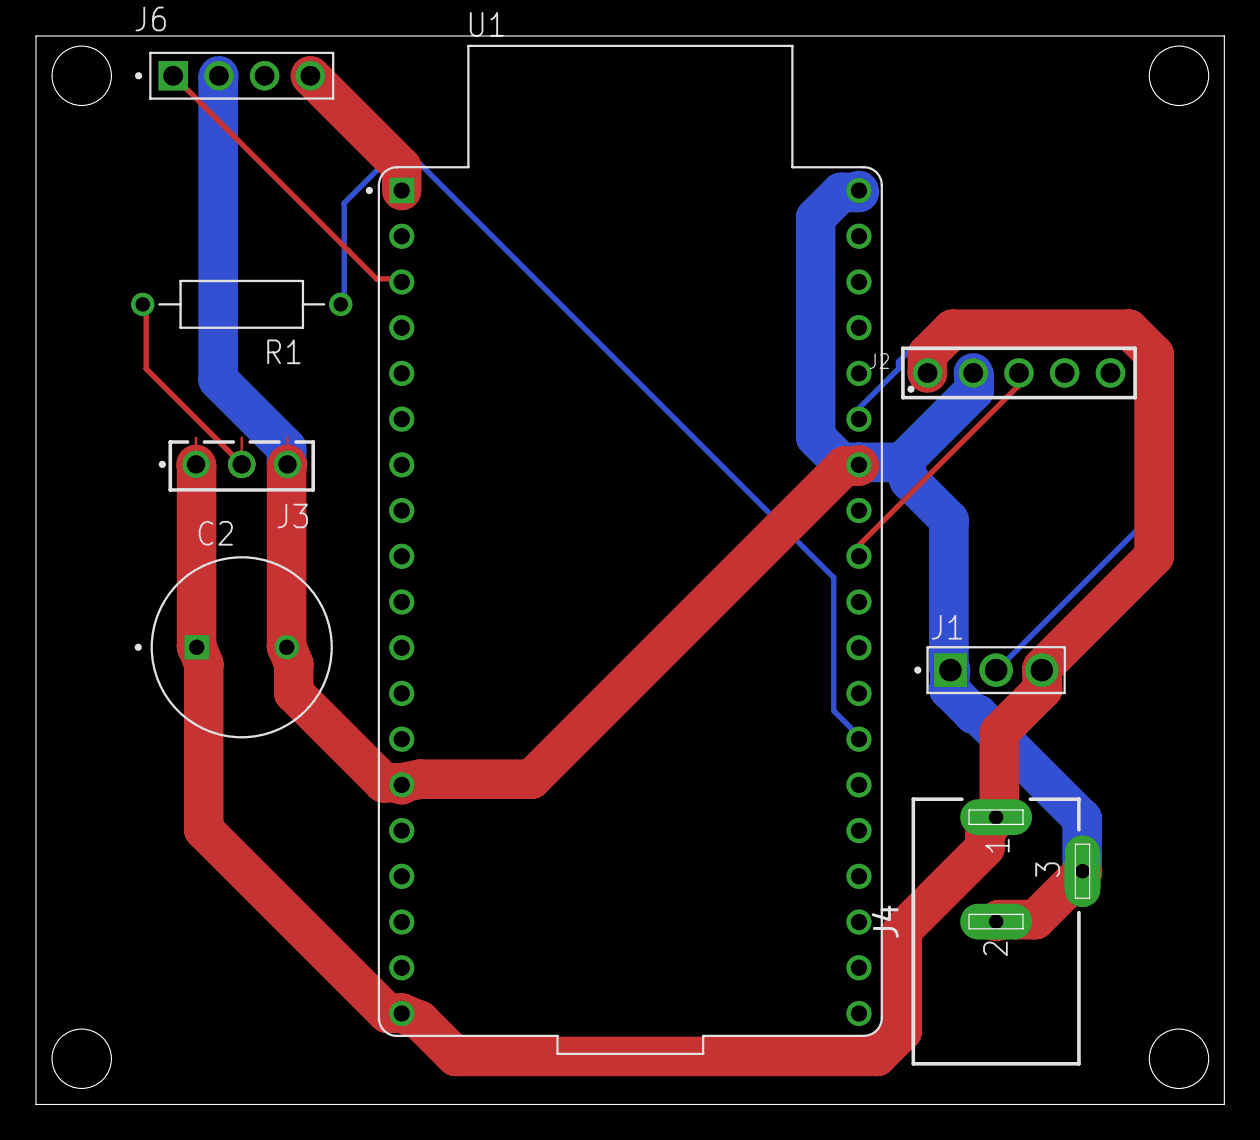
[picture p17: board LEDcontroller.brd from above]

Board: 2 copper layers, 66.0 x 59.4 mm, 8 parts (0 on the bottom side), 8 nets.

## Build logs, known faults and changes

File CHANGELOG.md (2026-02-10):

# CHANGELOG

## Wersja 1.0 – 2025-10-13
- Utworzenie podstawowej koncepcji projektu
- Wybór mikrokontrolera ESP32
- Ogólne założenia projektu

## Wersja 1.1 – 2025-10-27
- Stworzenie schematu blokowego
- Dobór czujników

## Wersja 1.2 – 2025-11-24
- Stworzenie schematu w programie Eagle
- Kompletowanie elementów elektronicznych

## Wersja 1.3 – 2026-01-19
- Prezentacja biznesowa

## Wersja 1.4 – 2026-01-28
- Zaprogramowanie działania układu
- Implementacja serwera WWW

## Wersja 1.5 – 2026-01-29
- Przylutowanie układu to płytki PCB
- Sprawdzenie poprawności działania układu

## Wersja 1.6 - 2026-02-02
- Prezentacja projektu
